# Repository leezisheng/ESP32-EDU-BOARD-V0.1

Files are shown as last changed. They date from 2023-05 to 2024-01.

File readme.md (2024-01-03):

# 开发板介绍

	开发板以ESP32 WROOM最小系统板为核心，板载5V降压稳压模块和供电指示电路、RS485通信模块、摇杆模块、OLED显示模块、气体传感器接口、DTH11温湿度传感器模块、18650电池盒、蜂鸣器驱动电路和按键及LED驱动电路组成。

	实物图如下所示：

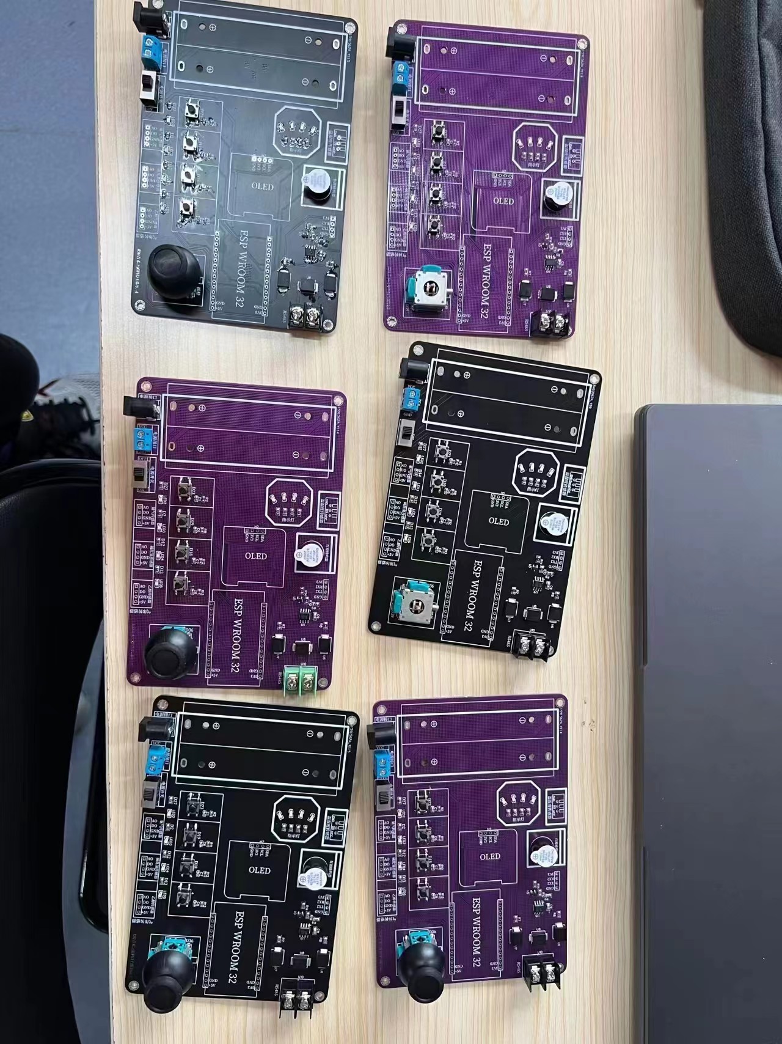
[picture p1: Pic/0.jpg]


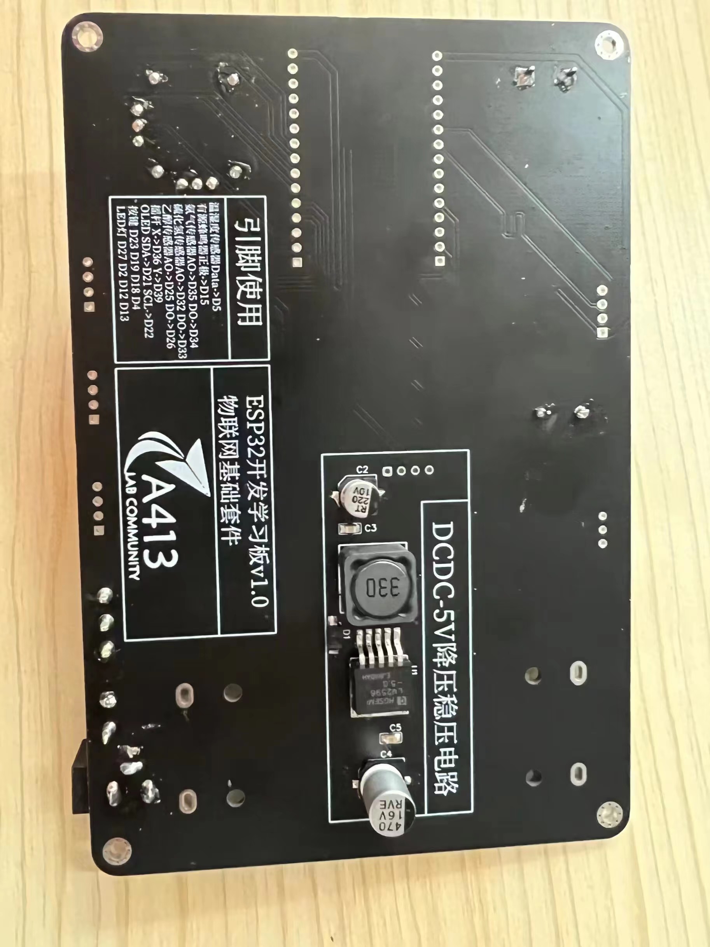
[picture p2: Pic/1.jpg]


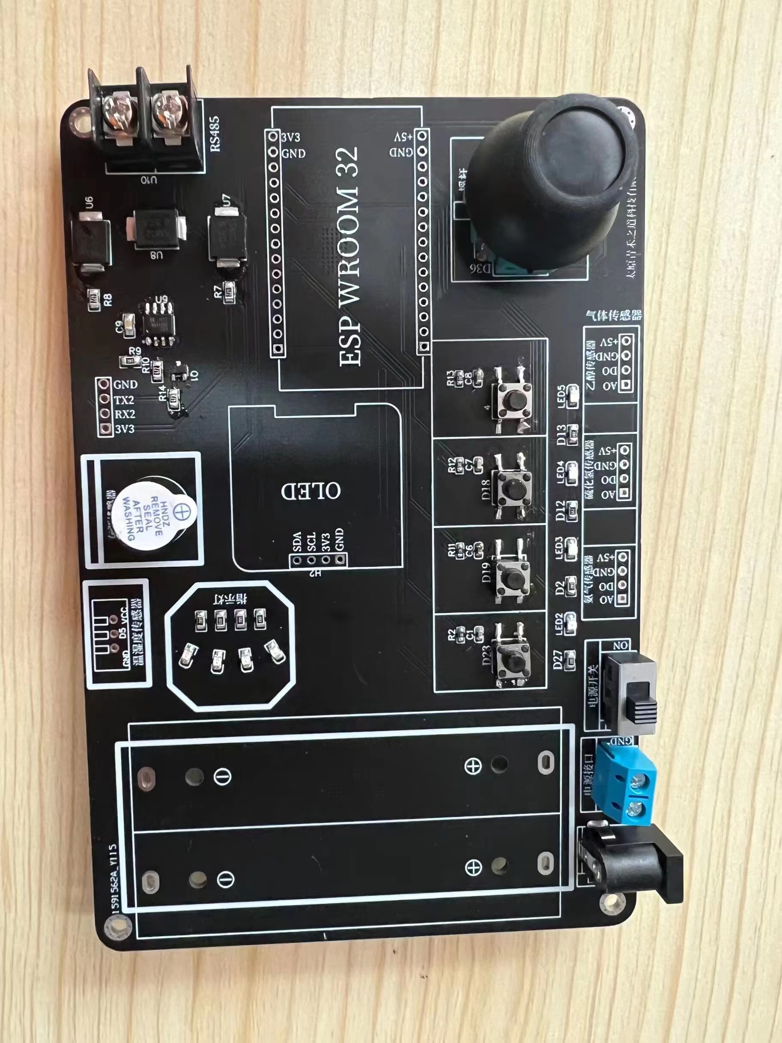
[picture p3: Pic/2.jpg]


	相关原理图如下：

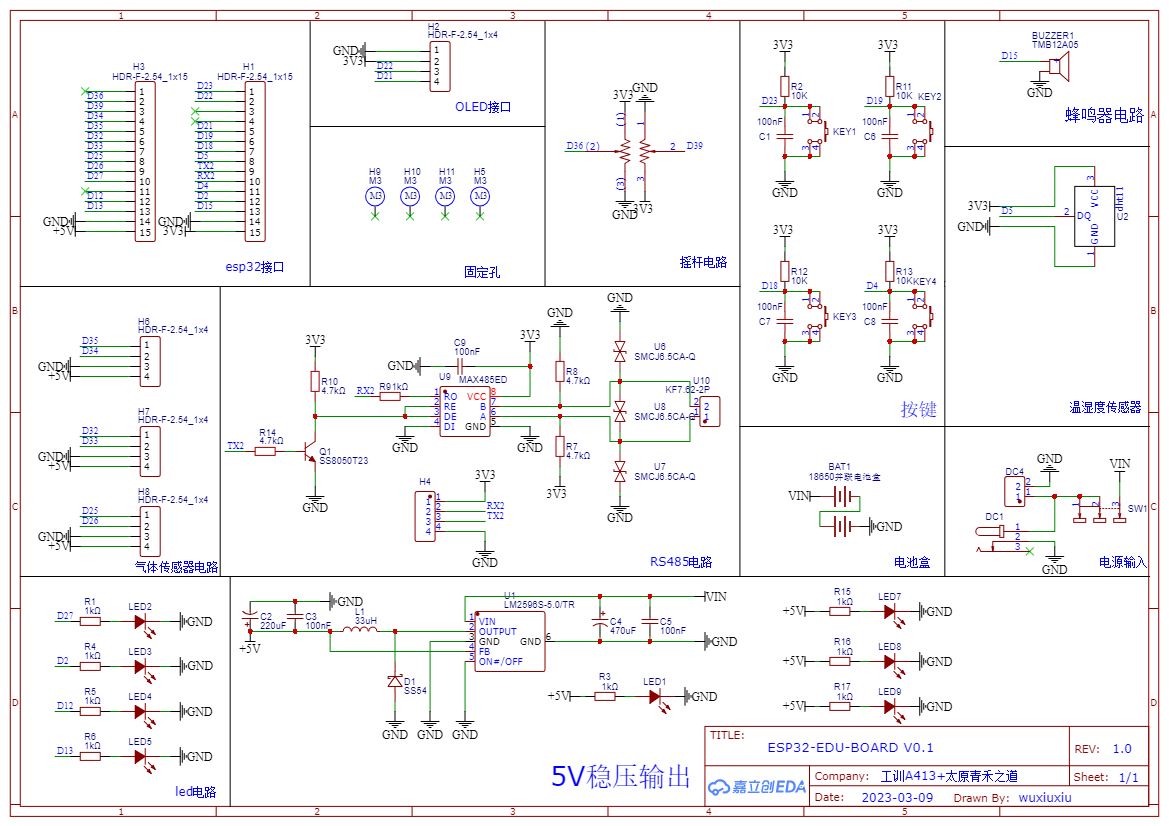
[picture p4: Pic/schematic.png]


	相关PCB的3D模型图如下：

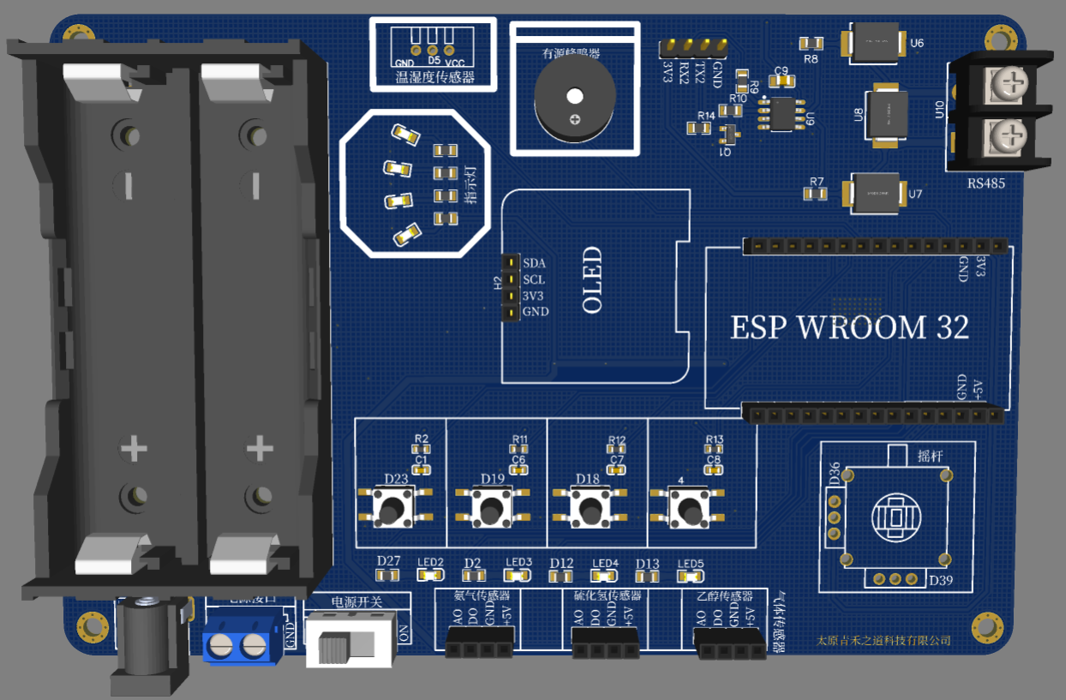
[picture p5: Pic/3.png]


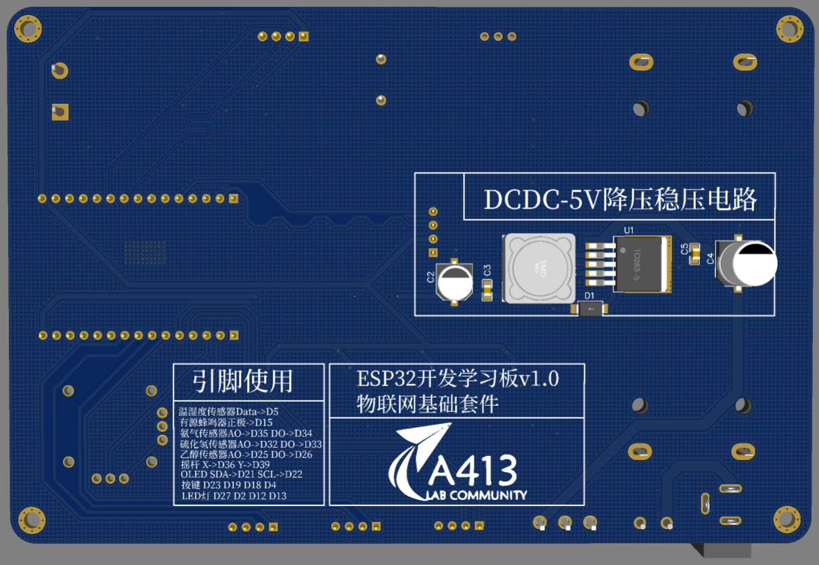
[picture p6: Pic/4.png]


# 文件夹介绍

  00 Demo：
  	相关软件例程，包括
   
		00 timer：定时器实验例程

		01 ammonia：ESP32 ADC外设数据读取，计算气体传感器浓度例程

		02 Bluetooth：ESP32蓝牙外设使用实验

		03 humiture：ESP32读取DTH11温湿度传感器数据实验

		04 key：ESP32 GPIO口外部中断实验

		05 rockerXY：ESP32 读取遥感位置实验

	01 Hardware：

		相关开发板的原理图和PCB图，及其工程文件

	02 Video：

		相关资料关注公众号：工训A座413，或者B站视频号：工训A413实验室

		软件相关课程：

			00 esp32制作循迹小车导论课

			https://www.bilibili.com/video/BV1X8411h7uW/?spm_id_from=333.999.0.0

			01 esp32第一课，用arduion安装esp32开发环境

			https://www.bilibili.com/video/BV1Wd4y1r7pR/?spm_id_from=333.999.0.0

			02 ESP32第二课之GPIO的输入输出

			https://www.bilibili.com/video/BV1J84y1y7jj/?spm_id_from=333.999.0.0

			03 ESP32第三课之外部中断

			https://www.bilibili.com/video/BV1424y127jU/?spm_id_from=333.999.0.0

		硬件相关课程：

			00 纳新培训（硬件篇）第一课：立创EDA基本使用

			https://www.bilibili.com/video/BV16P4y1X7go/?spm_id_from=333.999.0.0

			01 纳新培训（硬件篇）第二课：稳压电源电路

			https://www.bilibili.com/video/BV1iP411u7g7/?spm_id_from=333.999.0.0

			02  纳新培训（硬件篇）第三课：双H桥电机驱动电路

			https://www.bilibili.com/video/BV1iP411u7g7/?spm_id_from=333.999.0.0

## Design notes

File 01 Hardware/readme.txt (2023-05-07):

BOM单：PCB板使用元器件
ESP32-EDU-BOARD V0.1.json：PCB板原理图源文件，使用立创EDA标准版打开
ESP32-EDU-BOARD V0.1.pcbdoc：PCB板的layout文件，使用AD打开
原理图：PCB板原理图pdf和png文件
气体传感器板：气体传感器相关原理图和layout文件

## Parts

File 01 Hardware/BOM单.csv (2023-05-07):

ID | Name | Designator | Footprint | Quantity | Manufacturer Part | Manufacturer | Supplier | Supplier Part
1 | 18650并联电池盒 | BAT1 | BAT-TH_18650-2 | 1 | 18650并联电池盒 | null | LCSC | C9900010344
2 | TMB12A05 | BUZZER1 | BUZ-TH_BD12.0-P7.60-D0.6-FD | 1 | TMB12A05 | 华能 | LCSC | C96093
3 | 100nF | C1,C6,C7,C8 | C0603 | 4 | CC0603KRX7R9BB104 | YAGEO | LCSC | C14663
4 | 220uF | C2 | CAP-SMD_BD6.3-L6.6-W6.6-FD | 1 | RT1A221M0605 | ROQANG | LCSC | C267466
5 | 100nF | C3,C5,C9 | C0805 | 3 | CL21B104KBCNNNC | SAMSUNG | LCSC | C1711
6 | 470uF | C4 | CAP-SMD_BD8.0-L8.3-W8.3-FD | 1 | RVE1C471M0810 | ROQANG | LCSC | C107396
7 | SS54 | D1 | SMA_L4.3-W2.6-LS5.0-RD | 1 | SS54 | TWGMC | LCSC | C727065
8 | KH-DC-005-2.5 | DC1 | DC-IN-TH_KH-DC-005-2.5 | 1 | KH-DC-005-2.5 | kinghelm(金航标) | LCSC | C2847170
9 | KF301-5.0-2P | DC4 | CONN-TH_P5.00_KF301-5.0-2P | 1 | KF301-5.0-2P | Cixi Kefa Elec | LCSC | C474881
10 | HDR-F-2.54_1x15 | H1,H3 | HDR-F-2.54_1X15 | 2 |  |  | LCSC | C124408
11 | HDR-F-2.54_1x4 | H2,H6,H7,H8 | HDR-F-2.54_1X4 | 4 |  |  | LCSC | C225501
12 | 12251104CNSNS295001 | H4 | HDR-TH_4P-P2.54-V-M-1 | 1 | 12251104CNSNS295001 | JILN(锦凌) | LCSC | C355292
13 | M3 | H5,H9,H10,H11 | M3 | 4
14 | K4-6×6_SMD | KEY1,KEY2,KEY3,KEY4 | KEY-SMD_4P-L6.0-W6.0-P3.90-LS10.0 | 4 | K2-6639SP-D4SC-04 | 韩国韩荣 | LCSC | C191626
15 | 33uH | L1 | IND-SMD_L12.0-W12.0 | 1 | SLH1207S330MTT | Sunltech Tech | LCSC | C181844
16 | FC-2012HRK-620D | LED1,LED2,LED3,LED4,LED5,LED7,LED8,LED9 | LED0805-RD_RED | 8 | FC-2012HRK-620D | NATIONSTAR | LCSC | C84256
17 | SS8050T23 | Q1 | SOT-23-3_L2.9-W1.3-P1.90-LS2.4-BR | 1 | SS8050T23 | Me-TECH(美台高科) | LCSC | C2939671
18 | 1kΩ | R1,R3,R4,R5,R6,R15,R16,R17 | R0805 | 8 | RS-05K102JT | FH | LCSC | C115302
19 | 10K | R2,R11,R12,R13 | R0603 | 4 | 0603WAF1002T5E | UniOhm | LCSC | C25804
20 | 4.7kΩ | R7,R8,R10,R14 | R0805 | 4 | PTFR0805B4K70N9 | RESI(开步睿思） | LCSC | C328444
21 | 1kΩ | R9 | R0805 | 1 | PTFR0805B1K00N9 | RESI(开步睿思） | LCSC | C328437
22 | SS-12D10L3 | SW1 | SW-TH_SS-12D10L3 | 1 | SS-12D10L3 | XKB Enterprise | LCSC | C319013
23 | 摇杆电位器 4方向 16*16 COPY COPY | SW2 | SW-TH_3D_1616_4 | 1 | 3D161 | HRO | LCSC | C92593
24 | LM2596S-5.0/TR | U1 | TO-263-5_L10.2-W8.6-P1.70-LS14.4-TL | 1 | LM2596S-5.0/TR | HGSEMI | LCSC | C194349
25 | 华为牛逼3 | U2 | DHT11 | 1 |  |  | SeeedStudio
26 | SMCJ6.5CA-Q | U6,U7,U8 | SMC_L6.9-W5.9-LS7.9-BI | 3 | SMCJ6.5CA-Q | BOURNS | LCSC | C1517967
27 | MAX485ED | U9 | SOP-8_L4.9-W3.9-P1.27-LS6.0-BL | 1 | MAX485ED | HTC | LCSC | C481667
28 | KF7.62-2P | U10 | CONN-TH_KF7.62-2P | 1 | KF7.62-2P | KEFA(科发) | LCSC | C707824

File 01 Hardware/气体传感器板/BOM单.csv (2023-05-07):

ID | Name | Designator | Footprint | Quantity | Manufacturer Part | Manufacturer | Supplier | Supplier Part | Price
1 | 100nf | C1,C2 | C0805 | 2 | CC0805JRX7R7BB104 | YAGEO(国巨) | LCSC | C520082 | 0.0616
2 | PH-00219 | H1,H2,H3 | HDR-TH_6P-P2.54-V-M-R2-C3-S2.54 | 3 | PH-00219 | Liansheng(连盛) | LCSC | C2685145 | 0.1882
3 | FC-3215HRK-620D | LED1 | LED-SMD_L3.2-W1.3-RD-EH2.1 | 1 | NCD1206R1 | 国星光电 | LCSC | C84270 | 0.128
4 | 33Ω | R1 | R0805 | 1 | 0805W8F330JT5E | UNI-ROYAL(厚声) | LCSC | C17634 | 0.0107
5 | 1MΩ | R2 | R0805 | 1 | RS-05K105JT | FH(风华) | LCSC | C131391 | 0.0073
6 | 1kΩ | R3,R5 | R0805 | 2 | PTFR0805B1K00N9 | RESI(开步睿思） | LCSC | C328437 | 1.0388
7 | 10kΩ | R4,R6 | R0603 | 2 | 0603WAF1002T5E | UniOhm | LCSC | C25804 | 0.0055
8 | 气体传感器-CJ | U4 | MQ2-CJ | 1
9 | LM358DRG4 | U2,U3 | SOIC-8_L5.0-W3.2-P1.27-LS8.3-BL | 2 | LM358DRG4 | Texas Instruments | LCSC | C350551 | 1.1701

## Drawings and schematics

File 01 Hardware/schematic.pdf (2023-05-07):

## 蜂鸣器电路

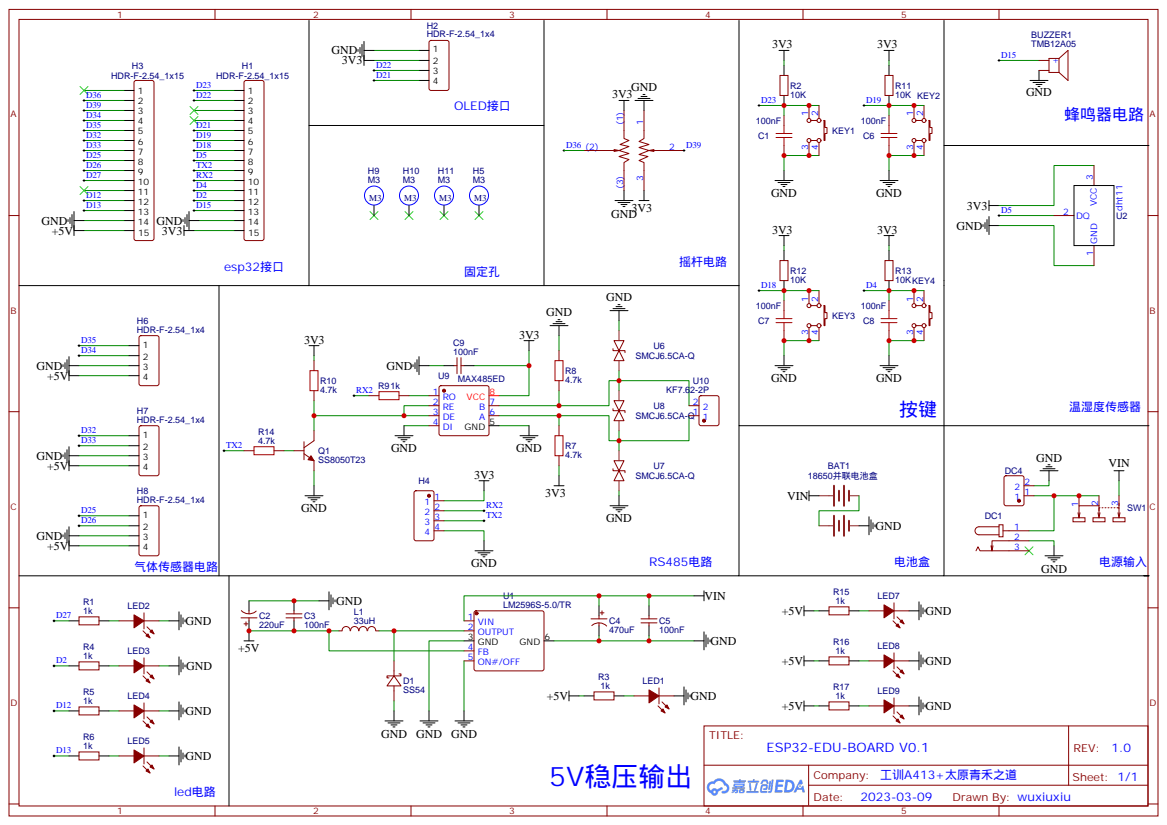
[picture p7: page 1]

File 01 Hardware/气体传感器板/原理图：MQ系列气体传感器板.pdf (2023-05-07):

MQ-136硫化氢 | MQ-7一氧化碳 | MQ-137氨气

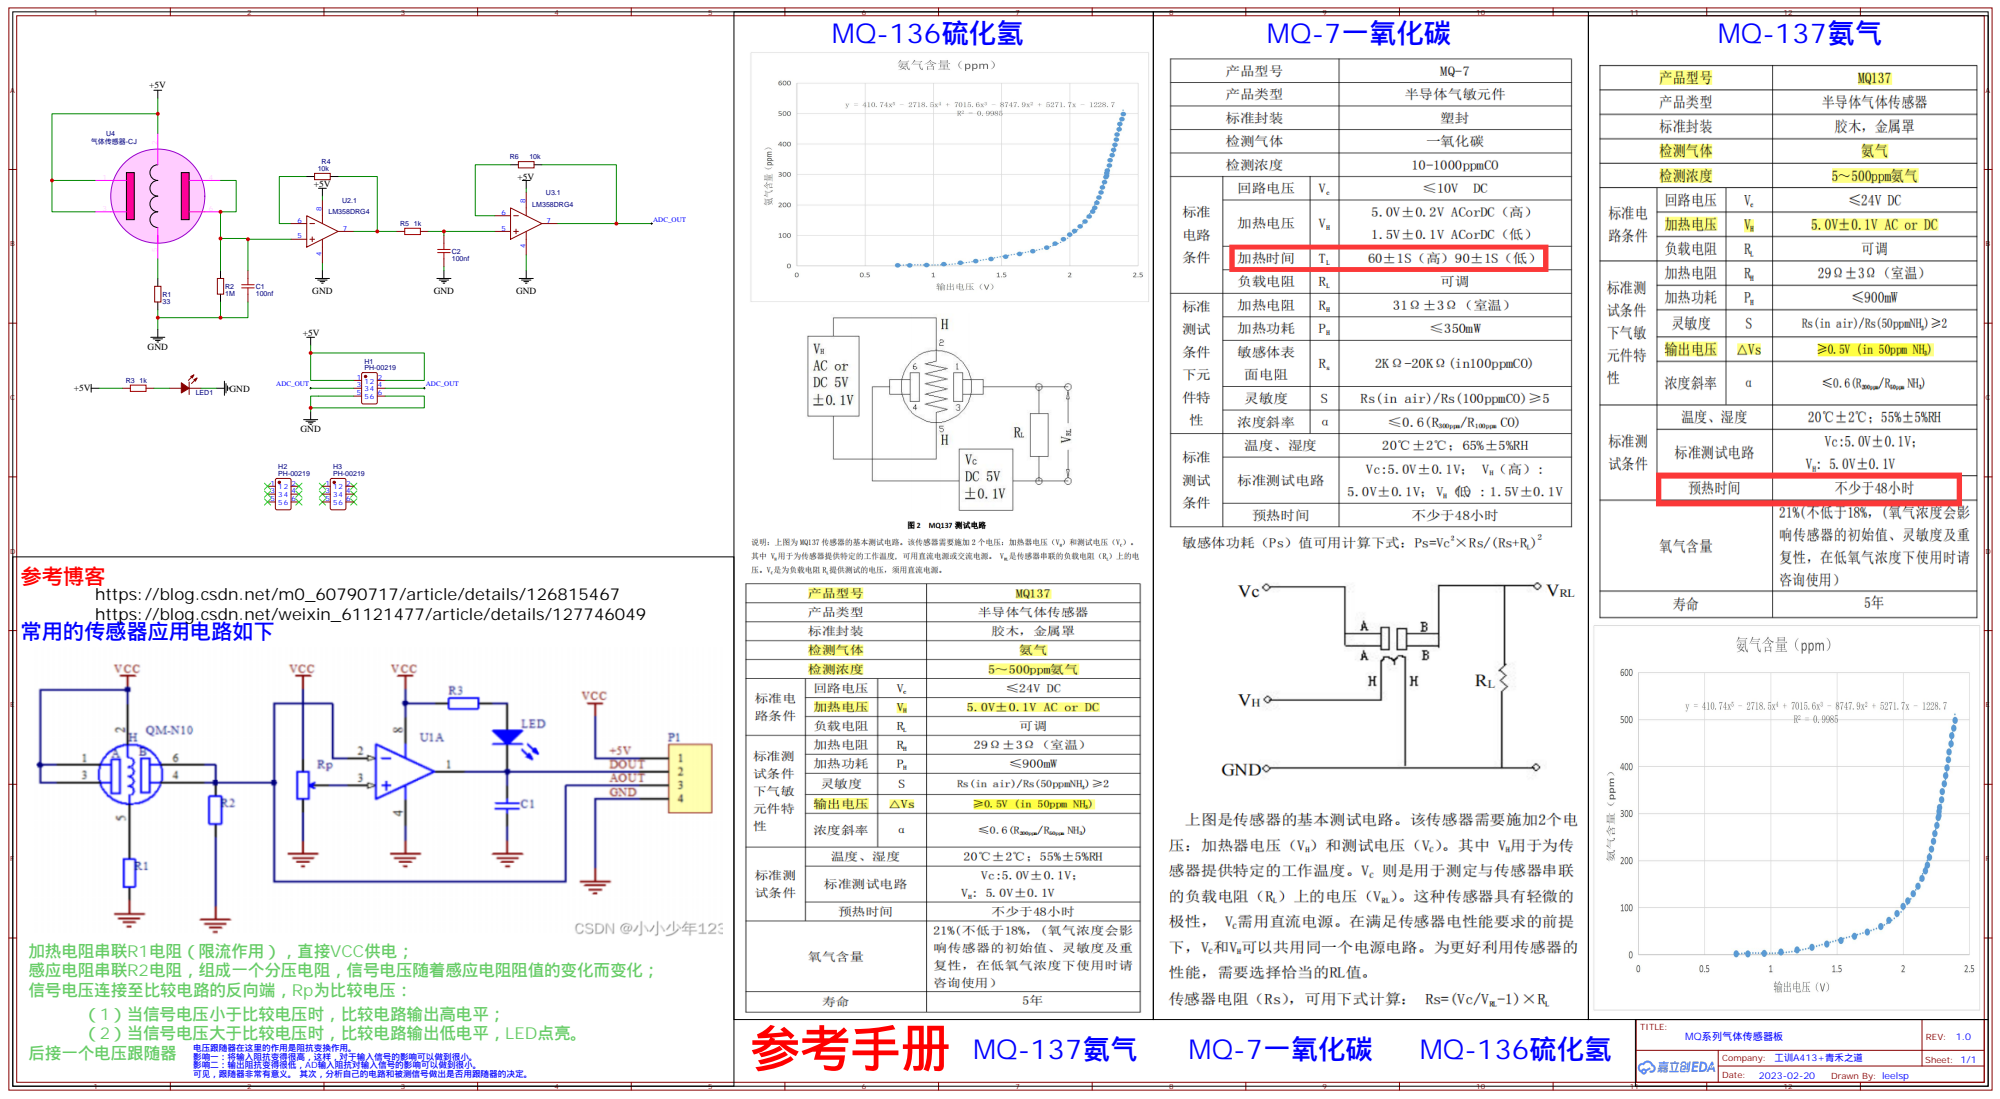
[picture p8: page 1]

https://blog.csdn.net/m0_60790717/article/details/126815467
https://blog.csdn.net/weixin_61121477/article/details/127746049

影响一：将输入阻抗变得很高，这样，对于输入信号的影响可以做到很小。
影响二：输出阻抗变得很低，AD输入阻抗对输入信号的影响可以做到很小。
可见，跟随器非常有意义。 其次，分析自己的电路和被测信号做出是否用跟随器的决定。

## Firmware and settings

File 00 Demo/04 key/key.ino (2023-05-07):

//定义针脚
#define key1 23
#define key2 19
#define key3 18
#define key4 4  //按键
#define LED2 27
#define LED3 2
#define LED4 12
#define LED5 13  //LED
//按键中断函数
void INTfunc1()
{
   digitalWrite(LED2,!digitalRead(LED2));
}
void INTfunc2()
{
   digitalWrite(LED3,!digitalRead(LED3));
}
void INTfunc3()
{
   digitalWrite(LED4,!digitalRead(LED4));
}
void INTfunc4()
{
   digitalWrite(LED5,!digitalRead(LED5));
}
void setup() {
  //LED
  pinMode(LED2,OUTPUT);
  digitalWrite(LED2,LOW);
  pinMode(LED3,OUTPUT);
  digitalWrite(LED3,LOW);
  pinMode(LED4,OUTPUT);
  digitalWrite(LED4,LOW);
  pinMode(LED5,OUTPUT);
  digitalWrite(LED5,LOW);
    //KEY
  pinMode(key1 ,INPUT_PULLUP);
  pinMode(key2 ,INPUT_PULLUP);
  pinMode(key3 ,INPUT_PULLUP);
  pinMode(key4 ,INPUT_PULLUP);
  attachInterrupt(key1,INTfunc1,RISING);
  attachInterrupt(key2,INTfunc2,RISING);
  attachInterrupt(key3,INTfunc3,RISING);
  attachInterrupt(key4,INTfunc4,RISING);
}

void loop() {
  
}

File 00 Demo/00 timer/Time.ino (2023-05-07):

#include <Arduino.h>
 
hw_timer_t *tim1 = NULL;
int tim1_IRQ_count = 0;
 
void tim1Interrupt()
{//中断服务函数
  Serial.println("haha");
  tim1_IRQ_count++;
  Serial.println(timerAlarmEnabled(tim1));
}
 
void setup()
{
  Serial.begin(115200);
  tim1 = timerBegin(0, 80, true);
  timerAttachInterrupt(tim1, tim1Interrupt, true);
  timerAlarmWrite(tim1, 100000ul, true);
  timerAlarmEnable(tim1);
}
 
void loop()
{
  if (tim1_IRQ_count > 10)
  {//相当于一秒触发一次
    Serial.println("定时器触发");
    tim1_IRQ_count = 0;
  }
}
